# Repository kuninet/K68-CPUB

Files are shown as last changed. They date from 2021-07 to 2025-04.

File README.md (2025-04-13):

# K68-CPUB

## 注意!! REV1基板はバグ多数です。REV2基板を使ってください。

* https://kuninet.org/2021/08/16/mc6800-cpu%e3%83%9c%e3%83%bc%e3%83%892-%e3%83%97%e3%83%aa%e3%83%b3%e3%83%88%e5%9f%ba%e6%9d%bf%e5%8c%96/

## 概要

* MC6800を使ったマイコンボードです。
  * MIKBUGオリジナルROMで動きます。
  * PIA MC6821/20をつかったシリアル通信が可能で、300bpsです。
* 10cm x 10cm サイズのプリント基板データがあります。基板固定穴は秋月電子Bサイズユニバーサル基板に合わせてあります。

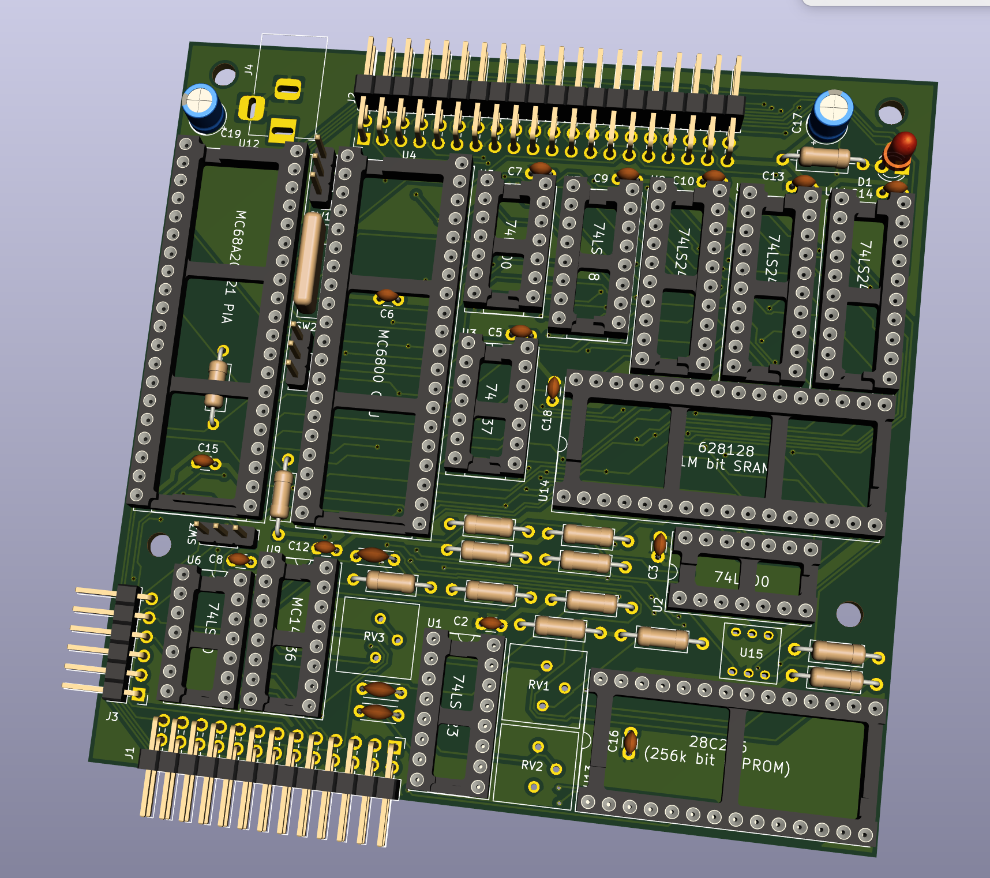
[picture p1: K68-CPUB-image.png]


## 部品・回路図など

* 部品表は以下のディレクトリに入っています。
  * KiCAD/K68-CPUB_BOM/BOM.csv
* 回路図PDFは以下のディレクトリに入っています。
  * KiCAD/K68-CPUB.pdf

## スイッチ、調整方法について
### スイッチ
* 基板上に以下のスイッチがあります。

| 記号 | スイッチ名 | 機能 |
| ---- | --- | --- |
| SW1  | 電源スイッチ | 電源のOFF/ON |
| SW2  | エコーバックSW | 通常はONにして使用してください。 |
| SW3  | ボーレートSW | 110bps/300bpsの切り替え。<br>ONで300bpsです。 |

### CPUクロック調整、シリアルクロック調整
#### CPUクロック
* 部品を組み付けたのち 74LS123のそばのRV1、RV2を調整して 700kHz～1MHzぐらいに調整してください。
* ※テスタ等の周波数カウンタをGNDとMC6800 CPUのPH1/PH2端子につないで調整してください。

### シリアルクロック
* 部品を組み付けたのち RV3を調整してください。300bpsにする場合は150Hzになるように調整してください。
* ※テスタ等の周波数カウンタをGNDとMC14536の13番ピンにつないで調整してください。

## 参考

* 書籍「マイコンの作り方・使い方」 啓学出版

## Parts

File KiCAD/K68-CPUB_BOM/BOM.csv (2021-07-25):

Reference | Value | Footprint | Datasheet
C1 | 100p | Capacitor_THT:C_Disc_D4.3mm_W1.9mm_P5.00mm | ~
C2 | 0.1u | Capacitor_THT:C_Disc_D3.0mm_W1.6mm_P2.50mm | ~
C3 | 0.1u | Capacitor_THT:C_Disc_D3.0mm_W1.6mm_P2.50mm | ~
C4 | 100p | Capacitor_THT:C_Disc_D4.3mm_W1.9mm_P5.00mm | ~
C5 | 0.1u | Capacitor_THT:C_Disc_D3.0mm_W1.6mm_P2.50mm | ~
C6 | 0.1u | Capacitor_THT:C_Disc_D3.0mm_W1.6mm_P2.50mm | ~
C7 | 0.1u | Capacitor_THT:C_Disc_D3.0mm_W1.6mm_P2.50mm | ~
C8 | 0.1u | Capacitor_THT:C_Disc_D3.0mm_W1.6mm_P2.50mm | ~
C9 | 0.1u | Capacitor_THT:C_Disc_D3.0mm_W1.6mm_P2.50mm | ~
C10 | 0.1u | Capacitor_THT:C_Disc_D3.0mm_W1.6mm_P2.50mm | ~
C11 | 620p | Capacitor_THT:C_Disc_D4.3mm_W1.9mm_P5.00mm | ~
C12 | 0.1u | Capacitor_THT:C_Disc_D3.0mm_W1.6mm_P2.50mm | ~
C13 | 0.1u | Capacitor_THT:C_Disc_D3.0mm_W1.6mm_P2.50mm | ~
C14 | 0.1u | Capacitor_THT:C_Disc_D3.0mm_W1.6mm_P2.50mm | ~
C15 | 0.1u | Capacitor_THT:C_Disc_D3.0mm_W1.6mm_P2.50mm | ~
C16 | 0.1u | Capacitor_THT:C_Disc_D3.0mm_W1.6mm_P2.50mm | ~
C17 | 10u | Capacitor_THT:CP_Radial_D5.0mm_P2.50mm | ~
C18 | 0.1u | Capacitor_THT:C_Disc_D3.0mm_W1.6mm_P2.50mm | ~
C19 | 10u | Capacitor_THT:CP_Radial_D5.0mm_P2.50mm | ~
D1 | LED_ALT | LED_THT:LED_D3.0mm | ~
J1 | PIA Con | Connector_PinHeader_2.54mm:PinHeader_2x13_P2.54mm_Horizontal | ~
J2 | SBC68 BUS | Connector_PinHeader_2.54mm:PinHeader_2x20_P2.54mm_Horizontal | ~
J3 | SERIAL COn | Connector_PinHeader_2.54mm:PinHeader_1x06_P2.54mm_Horizontal | ~
J4 | Barrel_Jack_Switch | Connector_BarrelJack:BarrelJack_Horizontal | ~
R1 | 3.3k | Resistor_THT:R_Axial_DIN0207_L6.3mm_D2.5mm_P10.16mm_Horizontal | ~
R2 | 5k | Resistor_THT:R_Axial_DIN0207_L6.3mm_D2.5mm_P10.16mm_Horizontal | ~
R3 | 5k | Resistor_THT:R_Axial_DIN0207_L6.3mm_D2.5mm_P10.16mm_Horizontal | ~
R4 | 2.2k | Resistor_THT:R_Axial_DIN0207_L6.3mm_D2.5mm_P10.16mm_Horizontal | ~
R5 | 2.2k | Resistor_THT:R_Axial_DIN0207_L6.3mm_D2.5mm_P10.16mm_Horizontal | ~
R6 | 680 | Resistor_THT:R_Axial_DIN0207_L6.3mm_D2.5mm_P10.16mm_Horizontal | ~
R7 | 10 | Resistor_THT:R_Axial_DIN0207_L6.3mm_D2.5mm_P10.16mm_Horizontal | ~
R8 | 680 | Resistor_THT:R_Axial_DIN0207_L6.3mm_D2.5mm_P10.16mm_Horizontal | ~
R9 | 10 | Resistor_THT:R_Axial_DIN0207_L6.3mm_D2.5mm_P10.16mm_Horizontal | ~
R10 | 82k | Resistor_THT:R_Axial_DIN0207_L6.3mm_D2.5mm_P10.16mm_Horizontal | ~
R11 | 10k | Resistor_THT:R_Axial_DIN0207_L6.3mm_D2.5mm_P10.16mm_Horizontal | ~
R12 | 2.2k | Resistor_THT:R_Axial_DIN0207_L6.3mm_D2.5mm_P10.16mm_Horizontal | ~
R13 | 1k | Resistor_THT:R_Axial_DIN0207_L6.3mm_D2.5mm_P10.16mm_Horizontal | ~
R14 | 10k | Resistor_THT:R_Axial_DIN0207_L6.3mm_D2.5mm_P10.16mm_Horizontal | ~
RN1 | 10k | Resistor_THT:R_Array_SIP5 | http://www.vishay.com/docs/31509/csc.pdf
RV1 | 50k | Potentiometer_THT:Potentiometer_Bourns_3386P_Vertical | ~
RV2 | 50k | Potentiometer_THT:Potentiometer_Bourns_3386P_Vertical | ~
RV3 | 50k | Potentiometer_THT:Potentiometer_Bourns_3386P_Vertical | ~
SW1 | SW_SPDT | Connector_PinHeader_2.54mm:PinHeader_1x03_P2.54mm_Vertical | ~
SW2 | BOARD SW | Connector_PinHeader_2.54mm:PinHeader_1x03_P2.54mm_Vertical | ~
SW3 | ECHO SW | Connector_PinHeader_2.54mm:PinHeader_1x03_P2.54mm_Vertical | ~
U1 | 74LS123 | Package_DIP:DIP-16_W7.62mm_Socket | http://www.ti.com/lit/gpn/sn74LS123
U2 | 74LS00 | Package_DIP:DIP-14_W7.62mm_Socket | http://www.ti.com/lit/gpn/sn74ls00
U3 | 74LS37 | Package_DIP:DIP-14_W7.62mm_Socket | http://www.ti.com/lit/gpn/sn74ls00
U4 | MC6800 | Package_DIP:DIP-40_W15.24mm_Socket | http://pdf.datasheetcatalog.com/datasheet/motorola/MC68A00L.pdf
U5 | 74LS00 | Package_DIP:DIP-14_W7.62mm_Socket | http://www.ti.com/lit/gpn/sn74ls00
U6 | 74LS00 | Package_DIP:DIP-14_W7.62mm_Socket | http://www.ti.com/lit/gpn/sn74ls00
U7 | 74LS138 | Package_DIP:DIP-16_W7.62mm_Socket | http://www.ti.com/lit/gpn/sn74LS138
U8 | 74LS245 | Package_DIP:DIP-20_W7.62mm_Socket | http://www.ti.com/lit/gpn/sn74LS245
U9 | MC14536B | Package_DIP:DIP-16_W7.62mm_Socket
U10 | 74LS244 | Package_DIP:DIP-20_W7.62mm_Socket | http://www.ti.com/lit/gpn/sn74LS244
U11 | 74LS244 | Package_DIP:DIP-20_W7.62mm_Socket | http://www.ti.com/lit/gpn/sn74LS244
U12 | MC68A21 | Package_DIP:DIP-40_W15.24mm_Socket | http://pdf.datasheetcatalog.com/datasheet/motorola/6821.pdf
U13 | 28C256 | Package_DIP:DIP-28_W15.24mm_Socket | http://ww1.microchip.com/downloads/en/DeviceDoc/doc0006.pdf
U14 | 128k SRAM | Package_DIP:DIP-32_W15.24mm_Socket | http://www.futurlec.com/Datasheet/Memory/628128.pdf
U15 | PS-70N | PUSH_SW:SW_PUSH_PS-70N

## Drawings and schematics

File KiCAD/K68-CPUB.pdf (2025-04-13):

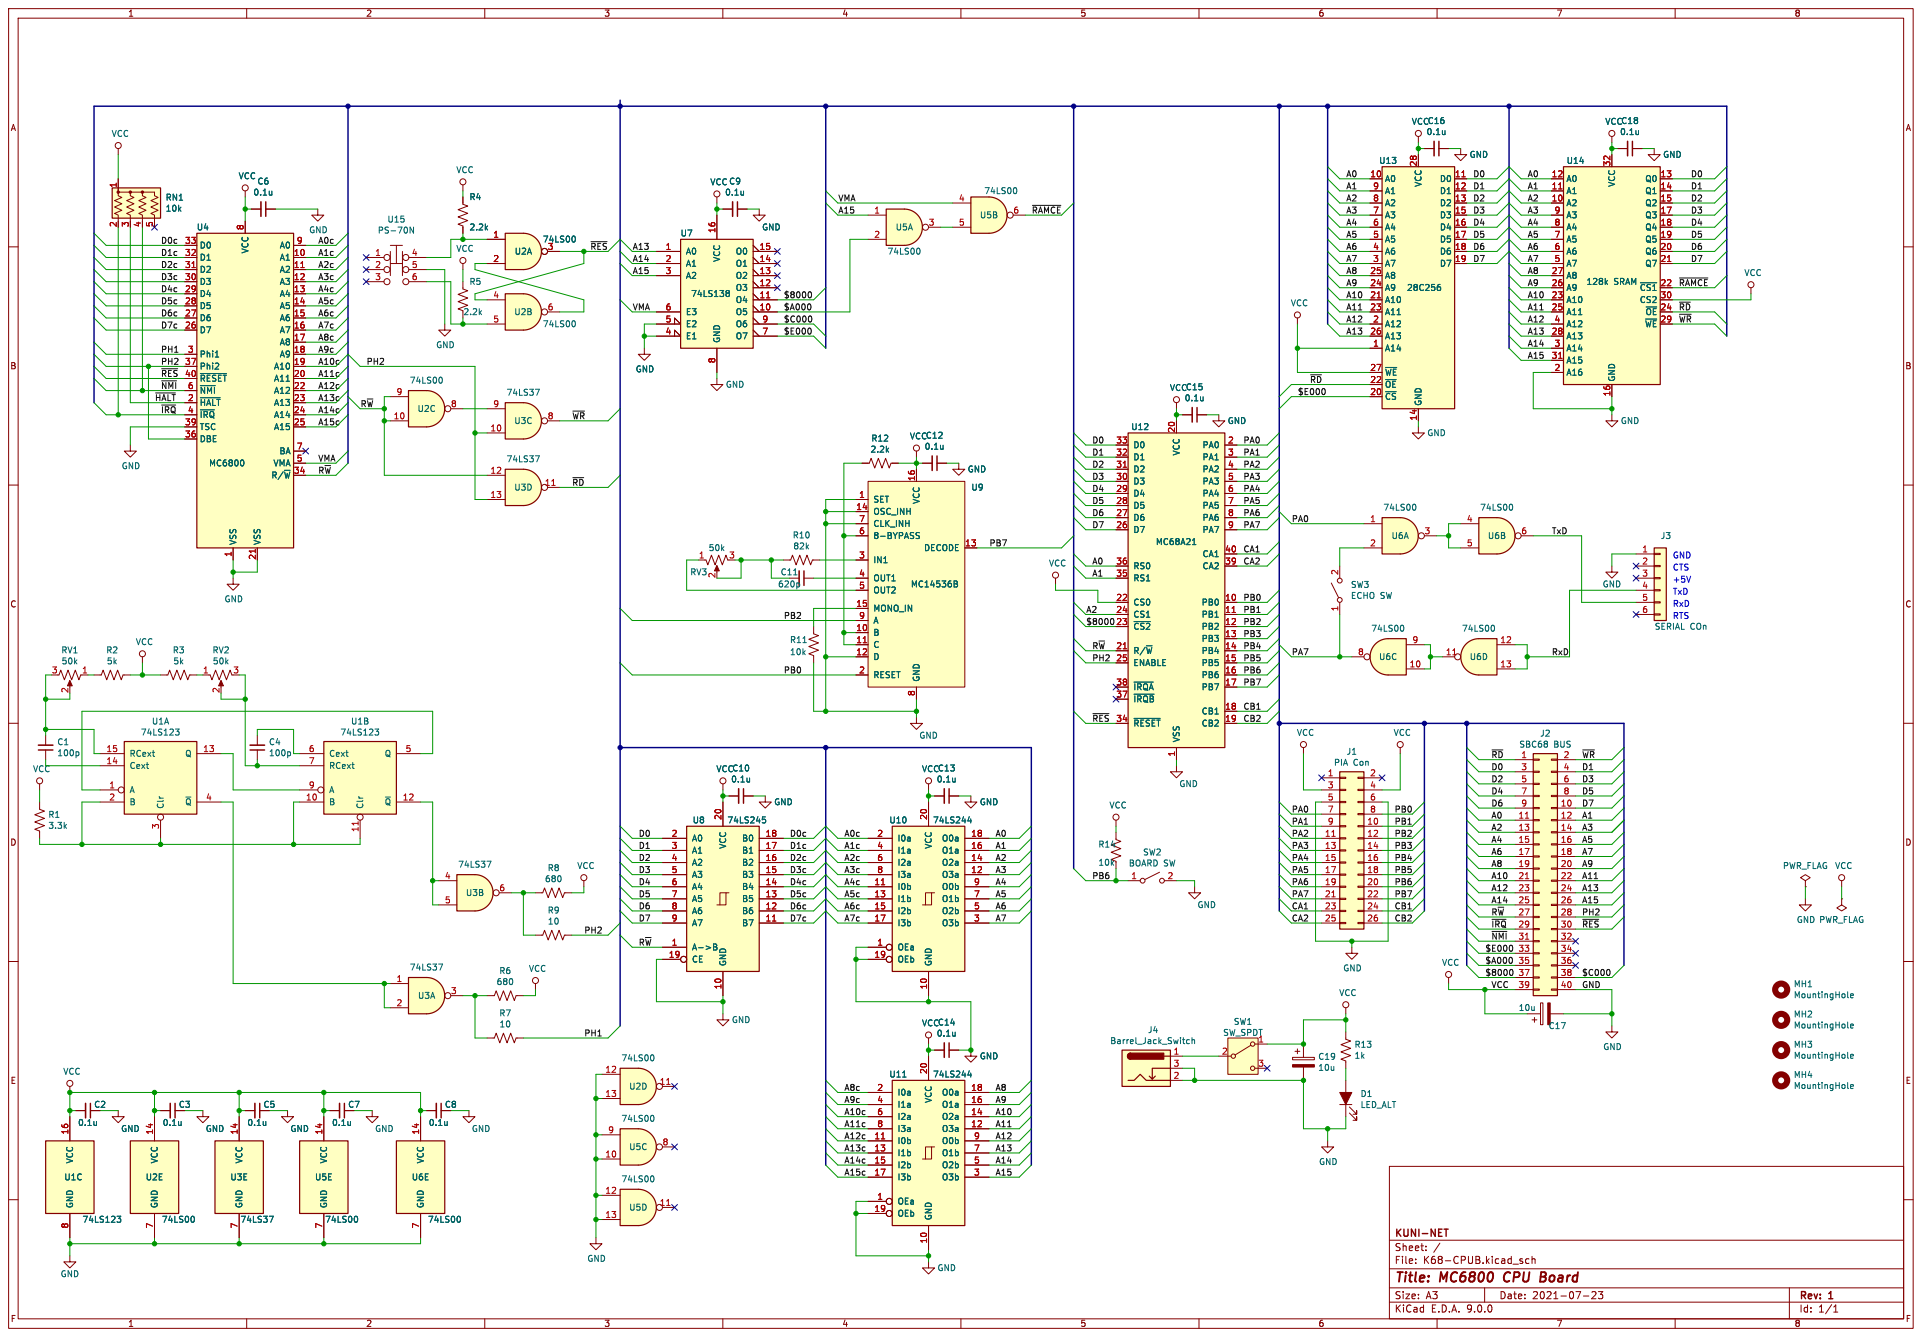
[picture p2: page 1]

1 2 SW3 ECHO SW VCC 32 GND 16 A0 12 A1 11 A2 10 A3 9 A4 8 A5 7 A6 6 A7 5 A8 27 A9 26 A10 23 A11 25 A12 4 A13 28 A14 3 A15 31 A16 2 Q0 13 Q1 14 Q2 15 Q3 17 Q4 18 Q5 19 Q6 20 Q7 21 ~{CS1}22 CS2 30 ~{OE} 24 ~{WE} 29 U14

File: K68-CPUB.kicad_sch Sheet: / KUNI-NET

Id: 1/1 Title: MC6800 CPU Board

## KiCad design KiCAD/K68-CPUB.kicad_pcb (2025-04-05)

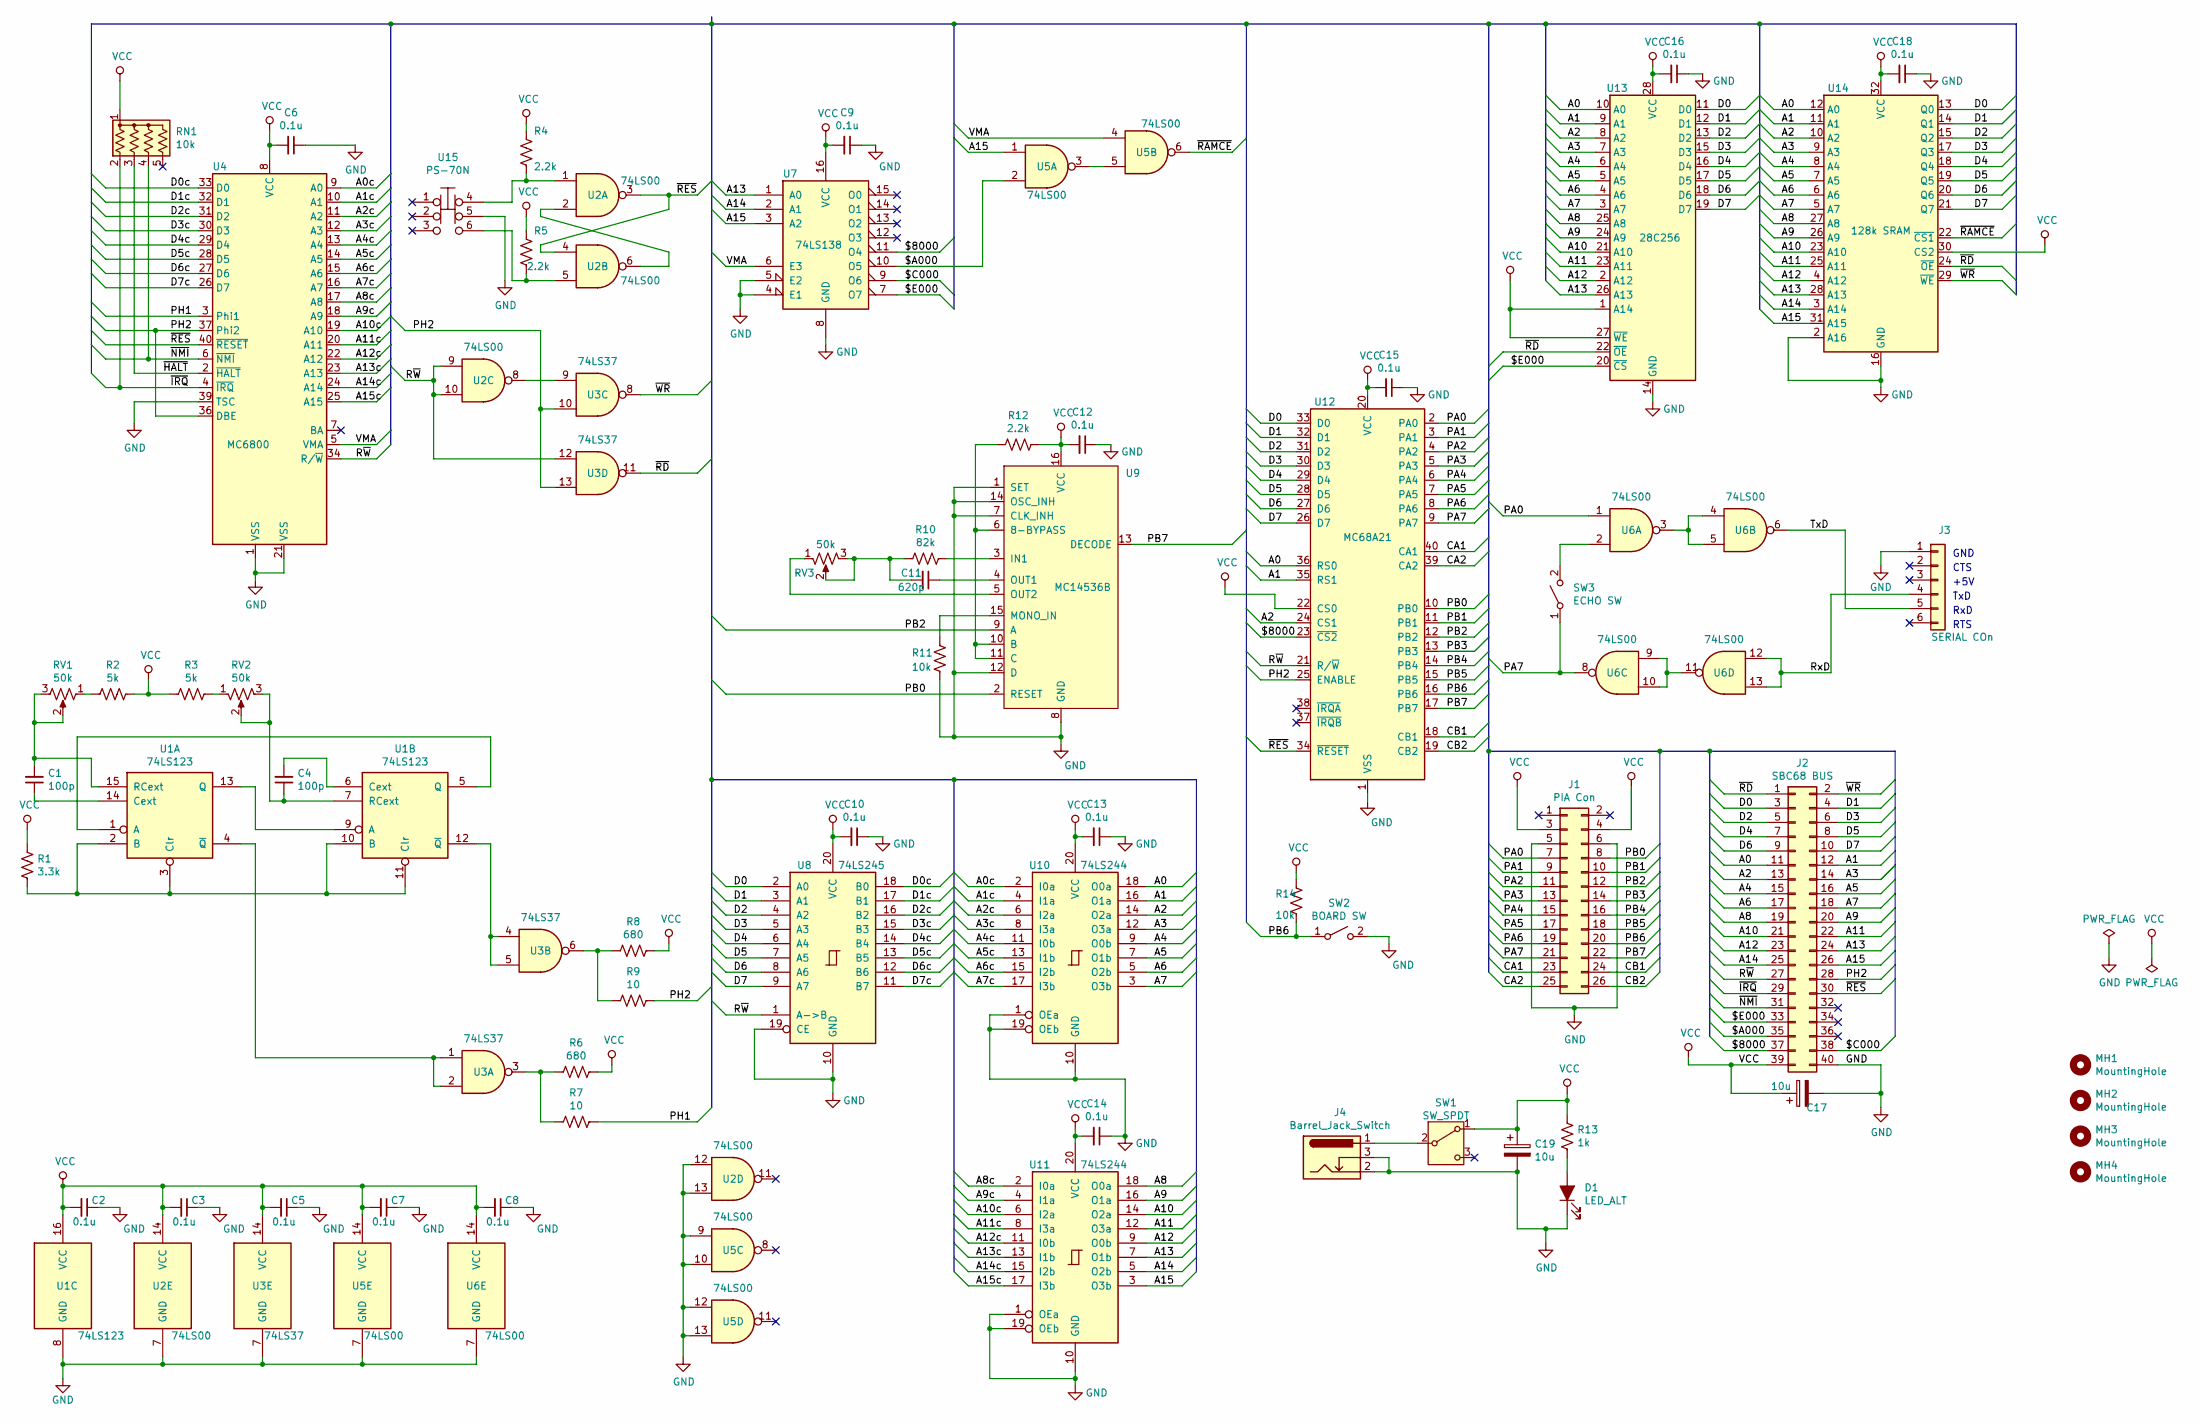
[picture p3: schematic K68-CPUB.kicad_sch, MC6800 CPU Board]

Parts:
C1, C4: 100p; C_Disc_D4.3mm_W1.9mm_P5.00mm
C2, C3, C5, C6, C7, C8, C9, C10, C12, C13, C14, C15, C16, C18: 0.1u; C_Disc_D3.0mm_W1.6mm_P2.50mm
C11: 620p; C_Disc_D4.3mm_W1.9mm_P5.00mm
C17, C19: 10u; CP_Radial_D5.0mm_P2.50mm
D1: LED_ALT; LED_D3.0mm
J1: PIA Con; PinHeader_2x13_P2.54mm_Horizontal
J2: SBC68 BUS; PinHeader_2x20_P2.54mm_Horizontal
J3: SERIAL COn; PinHeader_1x06_P2.54mm_Horizontal
J4: Barrel_Jack_Switch; BarrelJack_Horizontal
MH1, MH2, MH3, MH4: MountingHole; MountingHole_3.2mm_M3
R1: 3.3k; R_Axial_DIN0207_L6.3mm_D2.5mm_P10.16mm_Horizontal
R2, R3: 5k; R_Axial_DIN0207_L6.3mm_D2.5mm_P10.16mm_Horizontal
R4, R5, R12: 2.2k; R_Axial_DIN0207_L6.3mm_D2.5mm_P10.16mm_Horizontal
R6, R8: 680; R_Axial_DIN0207_L6.3mm_D2.5mm_P10.16mm_Horizontal
R7, R9: 10; R_Axial_DIN0207_L6.3mm_D2.5mm_P10.16mm_Horizontal
R10: 82k; R_Axial_DIN0207_L6.3mm_D2.5mm_P10.16mm_Horizontal
R11, R14: 10k; R_Axial_DIN0207_L6.3mm_D2.5mm_P10.16mm_Horizontal
R13: 1k; R_Axial_DIN0207_L6.3mm_D2.5mm_P10.16mm_Horizontal
RN1: 10k; R_Array_SIP5
RV1, RV2, RV3: 50k; Potentiometer_Bourns_3386P_Vertical
SW1: SW_SPDT; PinHeader_1x03_P2.54mm_Vertical
SW2: BOARD SW; PinHeader_1x03_P2.54mm_Vertical
SW3: ECHO SW; PinHeader_1x03_P2.54mm_Vertical
U1: 74LS123; DIP-16_W7.62mm_Socket
U2, U5, U6: 74LS00; DIP-14_W7.62mm_Socket
U3: 74LS37; DIP-14_W7.62mm_Socket
U4: MC6800; DIP-40_W15.24mm_Socket
U7: 74LS138; DIP-16_W7.62mm_Socket
U8: 74LS245; DIP-20_W7.62mm_Socket
U9: MC14536B; DIP-16_W7.62mm_Socket
U10, U11: 74LS244; DIP-20_W7.62mm_Socket
U12: MC68A21; DIP-40_W15.24mm_Socket
U13: 28C256; DIP-28_W15.24mm_Socket
U14: 128k SRAM; DIP-32_W15.24mm_Socket
U15: PS-70N; SW_PUSH_PS-70N

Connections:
/$8000: J2.37, U7.11 (O4), U12.23 (~CS2)
/$A000: J2.35, U5.2, U7.10 (O5)
/$C000: J2.38, U7.9 (O6)
/$E000: J2.33, U7.7 (O7), U13.20 (~CS)
/A0: J2.11, U10.18 (O0a), U12.36 (RS0), U13.10 (A0), U14.12 (A0)
/A0c: U4.9 (A0), U10.2 (I0a)
/A1: J2.12, U10.16 (O1a), U12.35 (RS1), U13.9 (A1), U14.11 (A1)
/A1c: U4.10 (A1), U10.4 (I1a)
/A2: J2.13, U10.14 (O2a), U12.24 (CS1), U13.8 (A2), U14.10 (A2)
/A2c: U4.11 (A2), U10.6 (I2a)
/A3: J2.14, U10.12 (O3a), U13.7 (A3), U14.9 (A3)
/A3c: U4.12 (A3), U10.8 (I3a)
/A4: J2.15, U10.9 (O0b), U13.6 (A4), U14.8 (A4)
/A4c: U4.13 (A4), U10.11 (I0b)
/A5: J2.16, U10.7 (O1b), U13.5 (A5), U14.7 (A5)
/A5c: U4.14 (A5), U10.13 (I1b)
/A6: J2.17, U10.5 (O2b), U13.4 (A6), U14.6 (A6)
/A6c: U4.15 (A6), U10.15 (I2b)
/A7: J2.18, U10.3 (O3b), U13.3 (A7), U14.5 (A7)
/A7c: U4.16 (A7), U10.17 (I3b)
/A8: J2.19, U11.18 (O0a), U13.25 (A8), U14.27 (A8)
/A8c: U4.17 (A8), U11.2 (I0a)
/A9: J2.20, U11.16 (O1a), U13.24 (A9), U14.26 (A9)
/A9c: U4.18 (A9), U11.4 (I1a)
/A10: J2.21, U11.14 (O2a), U13.21 (A10), U14.23 (A10)
/A10c: U4.19 (A10), U11.6 (I2a)
/A11: J2.22, U11.12 (O3a), U13.23 (A11), U14.25 (A11)
/A11c: U4.20 (A11), U11.8 (I3a)
/A12: J2.23, U11.9 (O0b), U13.2 (A12), U14.4 (A12)
/A12c: U4.22 (A12), U11.11 (I0b)
/A13: J2.24, U7.1 (A0), U11.7 (O1b), U13.26 (A13), U14.28 (A13)
/A13c: U4.23 (A13), U11.13 (I1b)
/A14: J2.25, U7.2 (A1), U11.5 (O2b), U14.3 (A14)
/A14c: U4.24 (A14), U11.15 (I2b)
/A15: J2.26, U5.1, U7.3 (A2), U11.3 (O3b), U14.31 (A15)
/A15c: U4.25 (A15), U11.17 (I3b)
/CA1: J1.23, U12.40 (CA1)
/CA2: J1.25, U12.39 (CA2)
/CB1: J1.24, U12.18 (CB1)
/CB2: J1.26, U12.19 (CB2)
/D0: J2.3, U8.2 (A0), U12.33 (D0), U13.11 (D0), U14.13 (Q0)
/D0c: U4.33 (D0), U8.18 (B0)
/D1: J2.4, U8.3 (A1), U12.32 (D1), U13.12 (D1), U14.14 (Q1)
/D1c: U4.32 (D1), U8.17 (B1)
/D2: J2.5, U8.4 (A2), U12.31 (D2), U13.13 (D2), U14.15 (Q2)
/D2c: U4.31 (D2), U8.16 (B2)
/D3: J2.6, U8.5 (A3), U12.30 (D3), U13.15 (D3), U14.17 (Q3)
/D3c: U4.30 (D3), U8.15 (B3)
/D4: J2.7, U8.6 (A4), U12.29 (D4), U13.16 (D4), U14.18 (Q4)
/D4c: U4.29 (D4), U8.14 (B4)
/D5: J2.8, U8.7 (A5), U12.28 (D5), U13.17 (D5), U14.19 (Q5)
/D5c: U4.28 (D5), U8.13 (B5)
/D6: J2.9, U8.8 (A6), U12.27 (D6), U13.18 (D6), U14.20 (Q6)
/D6c: U4.27 (D6), U8.12 (B6)
/D7: J2.10, U8.9 (A7), U12.26 (D7), U13.19 (D7), U14.21 (Q7)
/D7c: U4.26 (D7), U8.11 (B7)
/PA0: J1.7, U6.1, U12.2 (PA0)
/PA1: J1.9, U12.3 (PA1)
/PA2: J1.11, U12.4 (PA2)
/PA3: J1.13, U12.5 (PA3)
/PA4: J1.15, U12.6 (PA4)
/PA5: J1.17, U12.7 (PA5)
/PA6: J1.19, U12.8 (PA6)
/PA7: J1.21, SW3.1 (A), U6.8, U12.9 (PA7)
/PB0: J1.8, U9.2 (RESET), U12.10 (PB0)
/PB1: J1.10, U12.11 (PB1)
/PB2: J1.12, U9.9 (A), U12.12 (PB2)
/PB3: J1.14, U12.13 (PB3)
/PB4: J1.16, U12.14 (PB4)
/PB5: J1.18, U12.15 (PB5)
/PB6: J1.20, R14.1, SW2.1 (A), U12.16 (PB6)
/PB7: J1.22, U9.13 (DECODE), U12.17 (PB7)
/PH1: R7.1, U4.3 (Phi1)
/PH2: J2.28, R9.1, U3.10, U3.13, U4.36 (DBE), U4.37 (Phi2), U12.25 (ENABLE)
/RxD: J3.4, U6.12, U6.13
/R~W: J2.27, U2.9, U2.10, U3.12, U4.34 (R/~W), U8.1 (A->B), U12.21 (R/~W)
/TxD: J3.5, U6.6
/VMA: U4.5 (VMA), U5.4, U7.6 (E3)
/~HALT: RN1.3 (R2), U4.2 (~HALT)
/~IRQ: J2.29, RN1.2 (R1), U4.4 (~IRQ)
/~NMI: J2.31, RN1.4 (R3), U4.6 (~NMI)
/~RAMCE: U5.6, U14.22 (~CS1)
/~RD: J2.1, U3.11, U13.22 (~OE), U14.24 (~OE)
/~RES: J2.30, U2.3, U2.4, U4.40 (~RESET), U12.34 (~RESET)
/~WR: J2.2, U3.8, U14.29 (~WE)
GND: C2.1, C3.1, C5.1, C6.1, C7.1, C8.1, C9.1, C10.1, C12.1, C13.1, C14.1, C15.1, C16.1, C17.2, C18.1, C19.2, D1.1 (K), J1.5, J1.6, J2.40, J3.1, J4.2, J4.3, R11.1, SW2.2 (B), U1.8 (GND), U2.7 (GND), U2.12, U2.13, U3.7 (GND), U4.1 (VSS), U4.21 (VSS), U4.39 (TSC), U5.7 (GND), U5.9, U5.10, U5.12, U5.13, U6.7 (GND), U7.4 (E1), U7.5 (E2), U7.8 (GND), U8.10 (GND), U8.19 (CE), U9.1 (SET), U9.7 (CLK_INH), U9.8 (GND), U9.12 (D), U9.14 (OSC_INH), U10.1 (OEa), U10.10 (GND), U10.19 (OEb), U11.1 (OEa), U11.10 (GND), U11.19 (OEb), U12.1 (VSS), U13.14 (GND), U14.2 (A16), U14.16 (GND), U15.5
unnamed: C11.2, R10.2, RV3.2, RV3.3
unnamed: D1.2 (A), R13.2
unnamed: R2.2, RV1.1
unnamed: R3.1, RV2.1
unnamed: R4.2, U2.1, U15.4
unnamed: R5.2, U2.5, U15.6
unnamed: R6.2, R7.2, U3.3
unnamed: R8.2, R9.2, U3.6
unnamed: J4.1, SW1.2 (B)
unnamed: SW3.2 (B), U6.2
unnamed: U1.1 (A), U1.5 (Q)
unnamed: R1.2, U1.2 (B), U1.3 (Clr), U1.10 (B), U1.11 (Clr)
unnamed: C1.1, U1.14 (Cext)
unnamed: U1.9 (A), U1.13 (Q)
unnamed: C1.2, RV1.2, RV1.3, U1.15 (RCext)
unnamed: U1.4 (~Q), U3.1, U3.2
unnamed: C4.2, U1.6 (Cext)
unnamed: C4.1, RV2.2, RV2.3, U1.7 (RCext)
unnamed: U1.12 (~Q), U3.4, U3.5
unnamed: U2.2, U2.6
unnamed: U2.8, U3.9
unnamed: U5.3, U5.5
unnamed: U6.3, U6.4, U6.5
unnamed: U6.9, U6.10, U6.11
unnamed: R12.2, U9.6 (8-BYPASS), U9.10 (B), U9.11 (C)
unnamed: R10.1, U9.3 (IN1)
unnamed: R11.2, U9.15 (MONO_IN)
unnamed: C11.1, U9.4 (OUT1)
unnamed: RV3.1, U9.5 (OUT2)
VCC: C2.2, C3.2, C5.2, C6.2, C7.2, C8.2, C9.2, C10.2, C12.2, C13.2, C14.2, C15.2, C16.2, C17.1, C18.2, C19.1, J1.3, J1.4, J2.39, R1.1, R2.1, R3.2, R4.1, R5.1, R6.1, R8.1, R12.1, R13.1, R14.2, RN1.1 (common), SW1.1 (A), U1.16 (VCC), U2.14 (VCC), U3.14 (VCC), U4.8 (VCC), U5.14 (VCC), U6.14 (VCC), U7.16 (VCC), U8.20 (VCC), U9.16 (VCC), U10.20 (VCC), U11.20 (VCC), U12.20 (VCC), U12.22 (CS0), U13.1 (A14), U13.27 (~WE), U13.28 (VCC), U14.30 (CS2), U14.32 (VCC)

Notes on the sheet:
RxD
+5V
GND
TxD
CTS
RTS

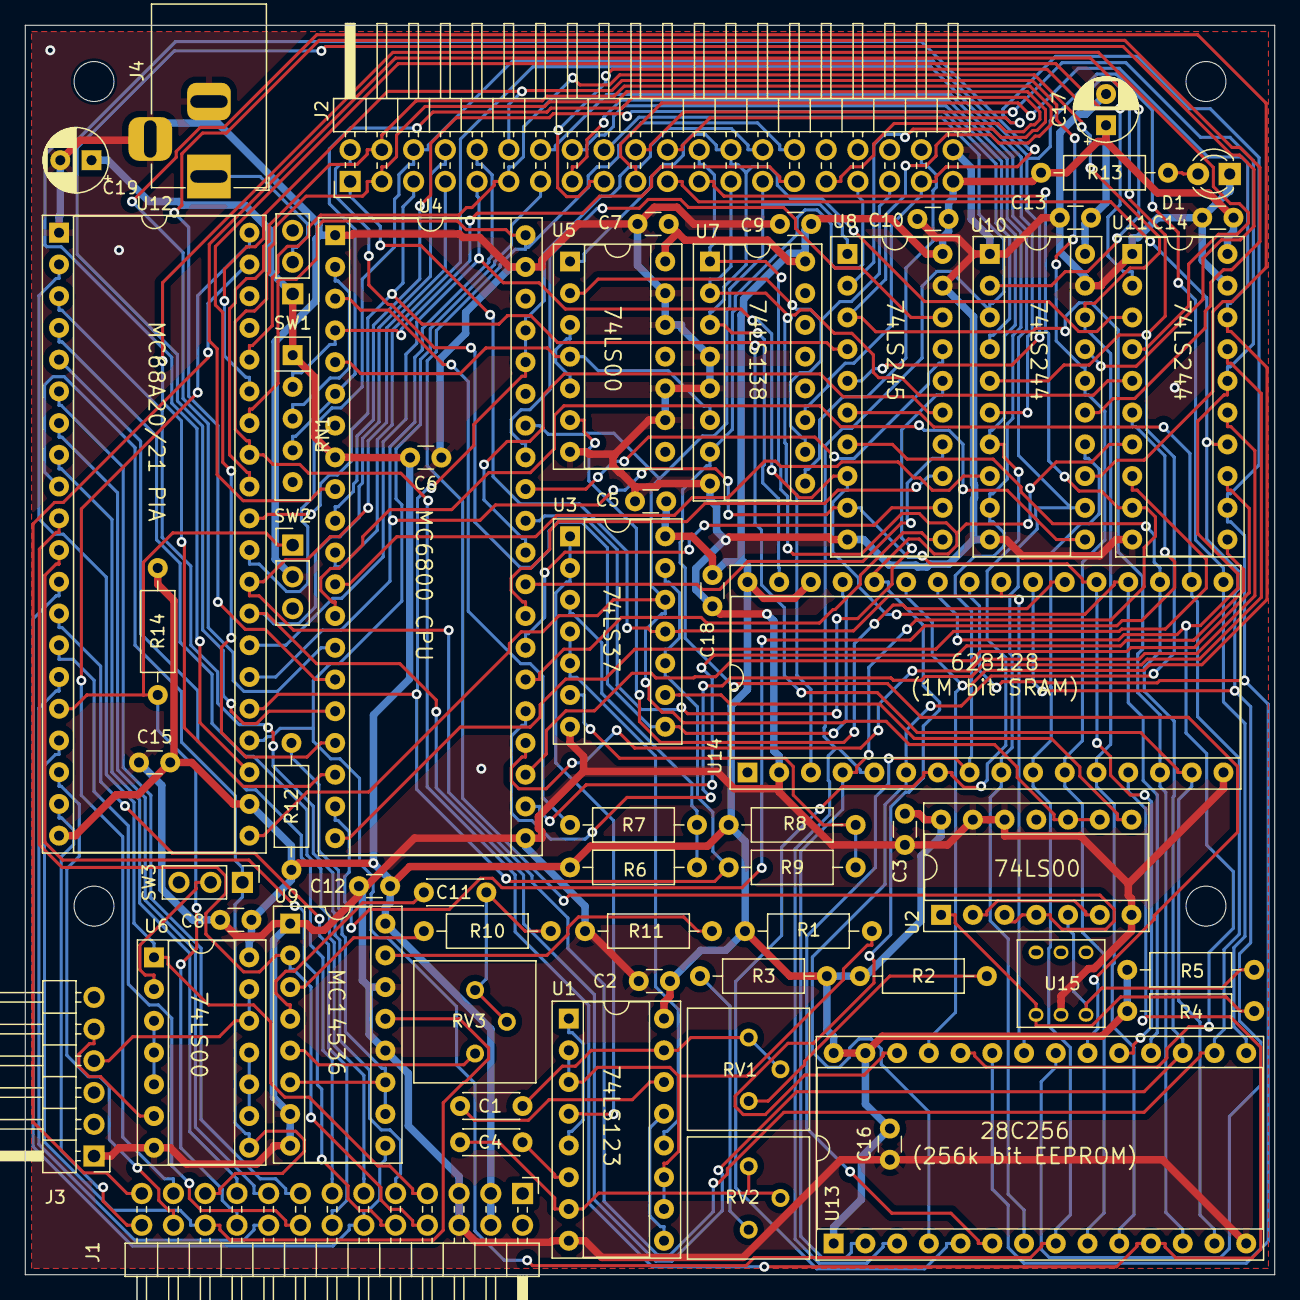
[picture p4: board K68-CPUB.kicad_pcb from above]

Board: 2 copper layers, 100.0 x 100.0 mm, 64 parts (0 on the bottom side), 116 nets.

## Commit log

2021-07-25 init commit
    [BOM.csv, K68-CPUB.dsn, K68-CPUB.kicad_pcb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]
2021-07-25 README等作成
2021-07-25 ガーバーデータ(仮) 生成
    [K68-CPUB.GBL, K68-CPUB.GBO, K68-CPUB.GBP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]
2021-07-25 基板イメージ追加
2021-07-25 基板裏面シルク追加・ガーバーデータ再作成
    [K68-CPUB.GBL, K68-CPUB.GBO, K68-CPUB.GBP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]
2024-04-21 回路バグ修正
    [K68-CPUB.dsn, K68-CPUB.kicad_sch]
2024-04-21 基板パターン修正中...
    [K68-CPUB.kicad_pcb]
2024-04-21 REV2 基板 ガーバー出力
    [K68-CPUB.GBL, K68-CPUB.GBO, K68-CPUB.GBP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]
2025-04-05 ビアのテンティングを変更してREV2ガーバー再出力
    [K68-CPUB-B_Cu.gbl, K68-CPUB-B_Mask.gbs, K68-CPUB-B_Silkscreen.gbo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]
2025-04-13 回路図REV2版PDF出力
2025-04-13 READMEにスイッチやクロック調整方法追記
